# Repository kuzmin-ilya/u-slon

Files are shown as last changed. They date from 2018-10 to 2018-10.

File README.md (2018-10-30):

# u-SLON electrical circuit

u-SLON is small laboratory electrostimulator.  
This project is a part of [x-SLON project](https://github.com/comcon1/x-SLON).  
Please address the maternal project for detailed description.

Device is rather small and is assembled simply. We use the standard firm enclosure and face draft for it is attached. 
Please consult [assembly.txt](case/assembly.txt).

**Scheme of the device output**

Programmator connection is inside the enclosure. Output plugs are only USB and 2 Jacks (6.3 mm).
Pulse output has contacts galvanically separated from the rest circuit. 
Trigger output has the contact with trigger pulses having the fixed positive amplitude and the ground contact.

U-SLON output

# Authors

Ilya Kuzmin <kuzmin.ilya@gmail.com>  
Peter Mamonov <pmamonov@gmail.com>  
Alexey Nesterenko <comcon1@protonmail.com>  

# Licensing

"u-SLON electrical circuit" project (I. Kuzmin, P. Mamonov, A. Nesterenko)
is released under license CC BY-SA 3.0.

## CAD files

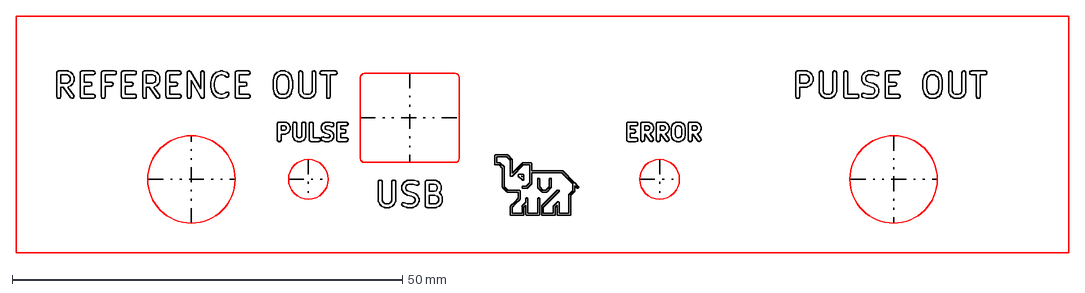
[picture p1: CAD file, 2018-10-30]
case/u-slon-face-final.dxf
134.9 x 30.3 mm

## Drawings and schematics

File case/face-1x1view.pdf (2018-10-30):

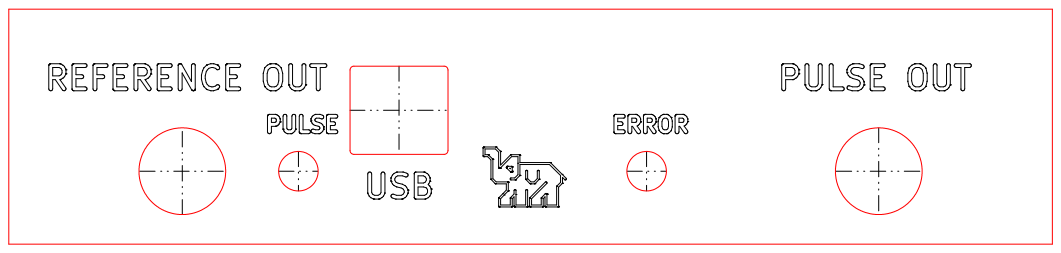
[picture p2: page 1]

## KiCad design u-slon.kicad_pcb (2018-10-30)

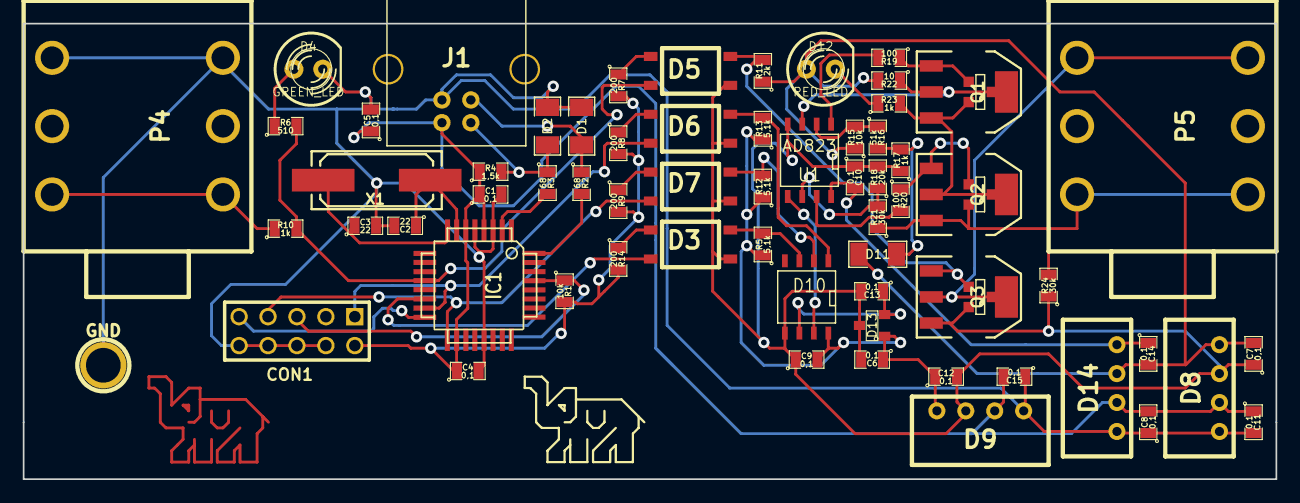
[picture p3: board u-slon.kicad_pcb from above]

Board: 2 copper layers, 110.0 x 40.0 mm, 67 parts (0 on the bottom side), 42 nets.

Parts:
C1, C4, C5, C6, C7, C8, C9, C10, C11, C12, C13, C14, C15: 0,1; SM0805
C2, C3: 22; SM0805
CON1: AVR-ISP-10; PIN_ARRAY_5x2
D1, D2, D11: 3,3V; SM1206
D3, D5, D6, D7: TLP181GB; TLP181
D4: GREEN_LED; LED-5MM
D8: P6AU-0512ELF; P6AU
D9, D14: P6AU-0505ELF; P6AU
D10: TLC5615CD; SO8N
D12: RED_LED; LED-5MM
D13: REF3020; SOT23
GND: P***; 1pin
IC1: ATMEGA8A-M; TQFP32
J1: USB_B
P4, P5: ST-020
Q1, Q2, Q3: IRFL4310; SOT223
R1, R15: 10k; SM0805
R2, R3: 68; SM0805
R4: 1,5k; SM0805
R5, R12, R13: 5,1k; SM0805
R6: 510; SM0805
R7, R8, R9, R14: 200; SM0805
R10, R17, R23: 1k; SM0805
R11: 2k; SM0805
R16: 51k; SM0805
R18: 20k; SM0805
R19, R20: 100; SM0805
R21, R24: 30k; SM0805
R22: 10; SM0805
SOT23GDS, SOT23GDS#2, SOT23GDS#3: VAL**; SOT23GDS
U1: AD823; SO8N
X1: 12MHz; Q_49U3HMS

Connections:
+5V: C1.1, C4.1, C5.1, C8.2, C11.1, C15.2, CON1.2, D8.2, D9.2, D14.2, IC1.4, IC1.6, IC1.18, J1.1, R1.2, R4.1, R7.2, R8.2, R9.2, R14.2
+5VA: C6.1, C9.2, C12.1, D9.4, D10.8, D13.1, R5.1, R12.1, R13.1
AGND: C6.2, C7.1, C9.1, C10.1, C12.2, C13.2, D3.4, D5.4, D6.4, D7.4, D8.3, D9.3, D10.5, D13.3, Q3.S, R17.1, R18.2, R24.1, U1.4
GND: C1.2, C2.2, C3.2, C4.2, C5.2, C8.1, C11.2, C15.1, CON1.4, CON1.6, CON1.8, CON1.10, D1.1, D2.1, D4.2, D8.1, D9.1, D14.1, IC1.3, IC1.5, IC1.21, J1.4, P4.1, P4.6
unnamed: CON1.1, D6.3, IC1.15
unnamed: D1.2, J1.3, R2.1
unnamed: R19.2, U1.1
unnamed: R20.2, U1.7
unnamed: CON1.9, IC1.16
unnamed: D2.2, J1.2, R3.1, R4.2
unnamed: IC1.32, R2.2
unnamed: IC1.2, R3.2
unnamed: D12.2, R23.1
unnamed: D6.6, D10.1, R13.2
unnamed: D4.1, R6.1
unnamed: P5.1, P5.6, Q3.D
unnamed: P4.3, P4.4, R10.1
unnamed: D10.7, U1.5
unnamed: D5.6, Q3.G, R11.2
unnamed: D7.6, D10.2, R12.2
unnamed: D7.1, R9.1
unnamed: D5.1, R7.1
unnamed: R18.1, R21.2, U1.6
unnamed: R15.2, R16.1, U1.2
unnamed: D11.1, R16.2, R17.2
unnamed: C13.1, D10.6, D13.2
unnamed: D6.1, R8.1
unnamed: Q1.S, Q2.D, R23.2
unnamed: Q1.D, R22.1, U1.3
unnamed: CON1.7, D7.3, IC1.17
unnamed: Q2.G, R20.1
unnamed: Q1.G, R19.1
unnamed: D3.6, D10.3, R5.2
unnamed: D3.3, IC1.14
unnamed: D3.1, R14.1
unnamed: P5.3, P5.4, Q2.S, R21.1, R24.2
unnamed: D5.3, IC1.12, R6.2, R10.2
unnamed: C10.2, C14.1, D14.4, U1.8
unnamed: C3.1, IC1.8, X1.2
unnamed: C2.1, IC1.7, X1.1
unnamed: CON1.5, IC1.29, R1.1
VCC: C7.2, C14.2, D8.4, D11.2, D12.1, D14.3, R11.1, R15.1, R22.2

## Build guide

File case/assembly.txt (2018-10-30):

The device is designed for packaging into Gainta G706 enclosure:
http://www.gainta.com/en/g706.html

The face panel can be made as PCB in the same order with the main board. In this case, use u-slon-face.kicad\_pcb.
Or it can be made with laser engraving; in this case, use u-slon-face-final.dxf.

The board is fixed at the panel, so you can use other enclosure just using the proper face panel.

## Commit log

2018-10-11 moving to git
    [u-slon.kicad_pcb, u-slon.sch]
2018-10-27 The face and the assemblage.
    [u-slon-face-final.dxf, u-slon-face.kicad_pcb]
2018-10-27 Face was extracted and removed from this file.
    [u-slon.kicad_pcb]
